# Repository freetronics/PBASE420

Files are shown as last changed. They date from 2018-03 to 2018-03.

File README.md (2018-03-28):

Freetronics ProtoBase 420
=========================
Copyright 2015 Freetronics Pty Ltd www.freetronics.com  

ProtoBase 420 is a prototyping circuit board designed to follow the
same format as common 400-point solderless breadboards. It can be
used by soldering parts in place, or a solderless breadboard can be
adhered to the top.

Includes a linear voltage regulator with switchable 3.3V / 5V output,
and a 2.1mm DC jack for power input.

Features:

 * Prototyping area
 * Switchable 3.3V / 5V voltage regulator
 * Power LED
 * 2.1mm DC power socket
 * Overlay guide where you need it (both top and bottom)
 * 3.2mm mounting holes for M3 bolts

You can view more at our product page at:

  http://www.freetronics.com/pbase420

INSTALLATION
------------
The design is saved as an EAGLE project. EAGLE PCB design software is
available from www.cadsoftusa.com free for non-commercial use. To use
this project download it and place the directory containing these files
into the "eagle" directory on your computer. Then open EAGLE and
navigate to Projects -> eagle -> PBASE420.

DISTRIBUTION
------------
The specific terms of distribution of this project are governed by the
license referenced below.

LICENSE
-------
Licensed under the TAPR Open Hardware License (www.tapr.org/OHL).
The "license" folder within this repository also contains a copy of
this license in plain text format.

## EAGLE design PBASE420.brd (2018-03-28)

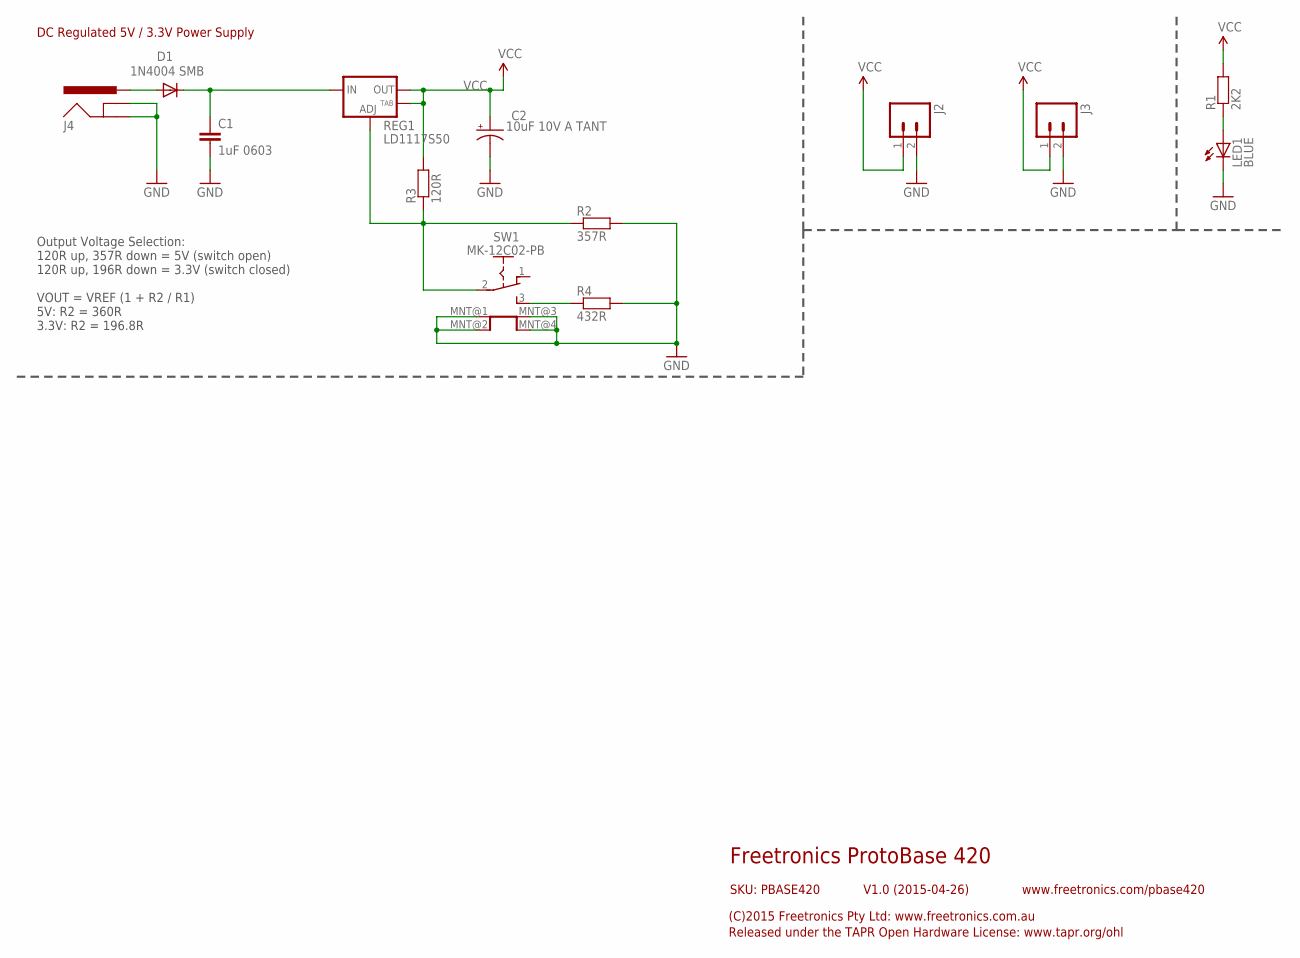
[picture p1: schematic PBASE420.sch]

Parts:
C1: 1uF 0603; 0603
C2: 10uF 10V A TANT; EIA3216
D1: 1N4004 SMB; SMB-DIODE
J2, J3: M02PTH; 1X02
J4: POWER_JACKPTH_SLOTS; POWER_JACK_PTH_SLOTS
LED1: BLUE; LED-0603
R1: 2K2; 0603
R2: 357R; 0603
R3: 120R; 0603
R4: 432R; 0603
REG1: LD1117S50; SOT223
SW1: MK-12C02-PB; MK-12C02

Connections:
GND: C1.2, C2.C (-), J2.2, J3.2, J4.GND, J4.GNDBREAK, LED1.C, R2.2, R4.2, SW1.MNT@1 (MNT), SW1.MNT@2 (MNT), SW1.MNT@3 (MNT), SW1.MNT@4 (MNT)
unnamed: LED1.A, R1.1
unnamed: R2.1, R3.1, REG1.1 (ADJ), SW1.2 (COM)
unnamed: R4.1, SW1.3 (B)
unnamed: D1.A, J4.PWR
VCC: C2.A (+), J2.1, J3.1, R1.2, R3.2, REG1.2 (OUT), REG1.4 (OUT)
VIN: C1.1, D1.C, REG1.3 (IN)

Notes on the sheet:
DC Regulated 5V / 3.3V Power Supply
Freetronics ProtoBase 420
V1.0 (2015-04-26)
SKU: PBASE420
(C)2015 Freetronics Pty Ltd: www.freetronics.com.au
Released under the TAPR Open Hardware License: www.tapr.org/ohl
www.freetronics.com/pbase420
Output Voltage Selection: 120R up, 357R down = 5V (switch open) 120R up, 196R down = 3.3V (switch closed) VOUT = VREF (1 + R2 / R1) 5V: R2 = 360R 3.3V: R2 = 196.8R

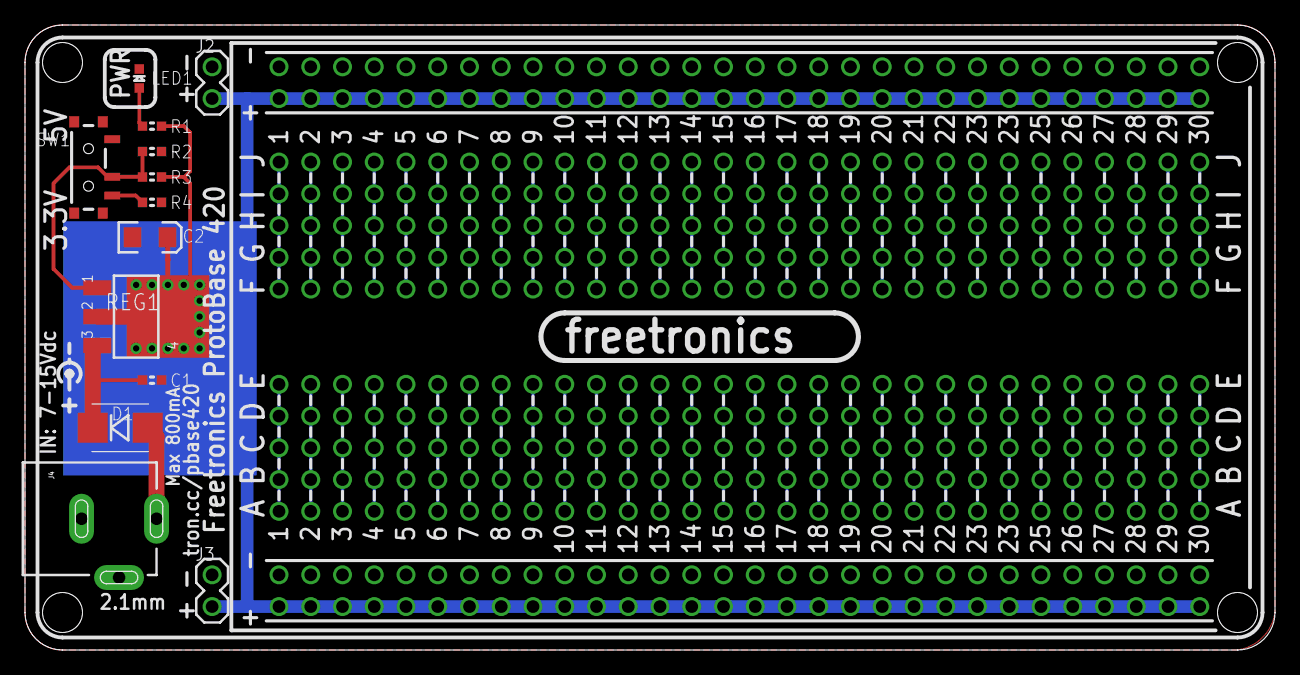
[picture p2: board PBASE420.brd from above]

Board: 2 copper layers, 100.0 x 50.0 mm, 13 parts (0 on the bottom side), 7 nets.

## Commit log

2015-04-26 Initial project import for v1.0 release
    [PBASE420.brd, PBASE420.sch]
2018-03-28 Updated silkscreen, designators, and README
    [PBASE420.brd, PBASE420.sch]
2018-03-28 Replaced DC jack footprint with slotted version
    [PBASE420.brd, PBASE420.sch]

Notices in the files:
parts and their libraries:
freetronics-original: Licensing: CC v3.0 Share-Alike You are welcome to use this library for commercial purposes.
